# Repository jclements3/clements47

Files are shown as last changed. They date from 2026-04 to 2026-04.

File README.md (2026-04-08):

# Clements47 Harp

A parametric Erard concert harp modeled in FreeCAD 1.1, with a soundbox defined by limacon cross-sections.

## Soundbox Surface Generation

The soundbox is defined by two planar curves and a family of limacon cross-sections swept between them.

### 1. Soundboard Curve (Limacon Origins)

A clamped cubic spline through 11 nodes with vertical takeoff (dx/dt = 0) at both endpoints.

**Nodes (base to neck):**

| # | Point | Description |
|---|---|---|
| 1 | (7.0, -65.6486) | Base — 3" left, 6" below C1 grommet |
| 2 | bass extension | 2" beyond string 1 along tangent |
| 3 | (10.0, -59.6486) | Grommet — string 1 (C1) |
| 4 | (14.943, -51.8946) | Grommet — string 8 |
| 5 | (20.512, -36.3672) | Grommet — string 16 |
| 6 | (25.476, -19.0939) | Grommet — string 24 |
| 7 | (30.076, -10.2416) | Grommet — string 32 |
| 8 | (34.313, -5.2852) | Grommet — string 40 |
| 9 | (37.986, -2.3942) | Grommet — string 47 (G7) |
| 10 | treble extension | 2" beyond string 47 along tangent |
| 11 | (40.3802, 0.0) | Neck — G7 string length right of G7 pin |

**Extension points** are computed from the tangent direction between the first/last two grommet nodes, extended 2" outward.

**Boundary conditions:** `bc_type=((1, 0.0), (1, 0.0))` for x(t), `bc_type=((1, v), (1, v))` for y(t), where v is the average parametric speed. This forces the curve to depart vertically at both the base and neck, ensuring the limacon cross-sections there lie flat (horizontal).

### 2. Cusp Curve (Limacon Cusps)

A clamped cubic spline through 9 nodes, also with vertical takeoff at both endpoints.

The 9 nodes are sampled from 51 cusp points. To compute each cusp point:

1. Evaluate the soundboard curve at the corresponding parameter value
2. Compute the unit tangent **(tx, ty)** and right-hand normal **(ty, -tx)**
3. Interpolate the limacon diameter linearly:
   - **18"** at the base (x = 7.0)
   - **4"** at the neck (x = 40.3802)
4. Compute **b = diameter / 6** (the polar axis length, since a = 2b)
5. Offset: **cusp = origin + b * right_normal**

The 9 nodes are taken at indices [0, 6, 12, 19, 25, 31, 37, 44, 50] of the 51 cusp points.

### 3. Limacon Cross-Sections

Each cross-section is a limacon of Pascal: **r(theta) = a + b * cos(theta)**

Given a pair of corresponding points (origin on soundboard curve, cusp on cusp curve):

- **b** = distance(origin, cusp) = polar axis length
- **a** = 2b (the a = 2b constraint ensures a smooth D-shape with no inner loop)
- **Polar axis direction** = unit vector from origin toward cusp
- **Limacon plane** is perpendicular to the soundboard tangent at that point

Orientation:
- **theta = 0**: points opposite the cusp (toward the strings / bulge side), r = a + b = 3b
- **theta = pi**: points toward the cusp, r = a - b = b

The 3D transformation for each point on the limacon:

```
u = r(theta) * cos(theta)    # component along polar axis (in XY plane)
v = r(theta) * sin(theta)    # component along Z axis

x = origin_x + u * (-polar_dir_x)
y = origin_y + u * (-polar_dir_y)
z = v
```

Where `polar_dir` is the unit vector from origin to cusp (so `-polar_dir` points toward the bulge at theta = 0).

### 4. Limacon Dimensions

| Property | Formula | Base (18" dia) | Neck (4" dia) |
|---|---|---|---|
| Diameter (max width) | 2(a + b) = 6b | 14" | 4" |
| Depth (along polar axis) | 4b | 9.3" | 2.67" |
| Bulge radius (theta=0) | a + b = 3b | 7" | 2" |
| Cusp distance (theta=pi) | a - b = b | 2.33" | 0.667" |
| Perpendicular width | 2a = 4b | 9.3" | 2.67" |
| Aspect ratio (width:depth) | 6b : 4b | 3:2 | 3:2 |

### 5. Acoustic Analysis

#### Volume and Helmholtz Resonance

| Property | Clements47 | Lyon & Healy 23 | Salvi Aurora |
|---|---|---|---|
| Soundbox volume | **43 L** | ~35-40 L | ~35-40 L |
| Helmholtz frequency | **85 Hz (E2)** | ~90-110 Hz | ~90-110 Hz |
| Base width | 14" | ~14-16" | ~14-16" |
| Total tension | 1,466 lbs | ~1,800 lbs | ~1,700 lbs |
| Cross-section | Limaçon (D-shape) | Round/Oval | Round/Oval |
| String material | Nylon/Wire | Gut/Wire | Gut/Wire |

#### Volume Distribution

| Region | Volume | Share |
|---|---|---|
| Base (0-15") | 1,628 in³ | 40% |
| Bass (15-30") | 1,127 in³ | 28% |
| Mid (30-50") | 882 in³ | 22% |
| Treble (50-65") | 315 in³ | 8% |
| Neck (65-75") | 97 in³ | 2% |

#### Soundboard Loading

- String angle from soundboard: 34°
- Vertical load: 820 lbs (56% of tension)
- Horizontal compression: 1,215 lbs (83% of tension)

#### Tonal Character

- **Warmer and rounder** than modern gut-strung concert harps
- **Enhanced bass** due to ~43L volume (1.2x modern harps)
- **Lower Helmholtz resonance** (~85 Hz vs 90-110 Hz) supports lower strings
- **D-shape projects directionally** — cusp acts as reflector toward player
- **Lighter tension** (1,466 lbs) allows thinner, more responsive soundboard
- Nylon strings: even decay across registers, less sustain than gut

#### Design Recommendations

- **Soundholes**: 2 holes (~3" dia) in the cusp (back), near strings 30-35
- **Soundboard**: Spruce, ~3mm (thinner than modern 4-5mm due to lower tension)
- **Bracing**: Minimal — limaçon cusp line provides natural stiffness
- **Back/ribs**: Maple, steam-bent or laminated to limaçon profile
- **Optional soundpost**: Bass end, connecting soundboard to cusp (violin-like coupling)

### 6. Lofting

50 limacon cross-sections are sampled evenly along the soundboard curve parameter and lofted into a solid using FreeCAD's `Part::Loft` with `Solid = True, Ruled = False`.

## Files

| File | Description |
|---|---|
| `erard_harp.FCMacro` | Stringband sketch (47 strings, keys, soundboard B-spline) |
| `erard_soundbox.FCMacro` | Soundbox generation (limacon cross-sections, loft) |
| `erard_harp.FCStd` | FreeCAD project with stringband sketch |
| `Clements47.FCStd` | FreeCAD project with soundbox |
| `erard%20original%20stringband%20tutorial.dxf` | Source string positions (harpcanada.com) |
| `soundboard_curve.svg` | 2D visualization of soundboard + cusp curves |

## Parameters

| Parameter | Value |
|---|---|
| Strings | 47 (C1 to G7) |
| String lengths | 59.65" (C1) to 2.39" (G7) |
| Base diameter | 14" |
| Neck diameter | 4" |
| Limacon ratio | a = 2b |
| Diameter taper | Linear |
| Extension length | 2" at each end |
| Base point offset | (-3, -6) from C1 grommet |
| Neck point offset | (+2.3942, 0) from G7 pin |
| Soundboard nodes | 11 (clamped cubic spline) |
| Cusp nodes | 9 (clamped cubic spline) |
| Cross-sections | 50 |
| Takeoff angles | 90" (vertical) at base and neck |

## Stringband Data

Source: [harpcanada.com/harpmaking/erard.htm](https://harpcanada.com/harpmaking/erard.htm)

### Note Map (47 strings, highest to lowest)

| Str# | Note | Octave | Material | Color | Spacing Group |
|---|---|---|---|---|---|
| 1 | G | 0 | Nylon | white | 0.706" |
| 2 | F | 0 | Nylon | blue | 0.706" |
| 3 | E | 1st | Nylon | white | 0.706" |
| 4 | D | 1st | Nylon | white | 0.706" |
| 5 | C | 1st | Nylon | **red** | 0.706" |
| 6 | B | 1st | Nylon | white | 0.706" |
| 7 | A | 1st | Nylon | white | 0.706" |
| 8 | G | 1st | Nylon | white | 0.706" |
| 9 | F | 1st | Nylon | blue | 0.706" |
| 10 | E | 2nd | Nylon | white | 0.706" |
| 11 | D | 2nd | Nylon | white | 0.706" |
| 12 | C | 2nd | Nylon | **red** | 0.686" |
| 13 | B | 2nd | Nylon | white | 0.686" |
| 14 | A | 2nd | Nylon | white | 0.686" |
| 15 | G | 2nd | Nylon | white | 0.686" |
| 16 | F | 2nd | Nylon | blue | 0.646" |
| 17 | E | 3rd | Nylon | white | 0.646" |
| 18 | D | 3rd | Nylon | white | 0.646" |
| 19 | C | 3rd | Nylon | **red** | 0.606" |
| 20 | B | 3rd | Nylon | white | 0.606" |
| 21 | A | 3rd | Nylon | white | 0.606" |
| 22 | G | 3rd | Nylon | white | 0.606" |
| 23 | F | 3rd | Nylon | blue | 0.606" |
| 24 | E | 4th | Nylon | white | 0.565" |
| 25 | D | 4th | Nylon | white | 0.565" |
| 26 | C | 4th | Nylon | **red** | 0.565" |
| 27 | B | 4th | Nylon | white | 0.565" |
| 28 | A | 4th | Nylon+wrap | white | 0.565" |
| 29 | G | 4th | Nylon+wrap | white | 0.565" |
| 30 | F | 4th | Nylon+wrap | blue | 0.565" |
| 31 | E | 5th | Nylon+wrap | white | 0.565" |
| 32 | D | 5th | Nylon+wrap | white | 0.565" |
| 33 | C | 5th | Nylon+wrap | **red** | 0.565" |
| 34 | B | 5th | Nylon+wrap | white | 0.525" |
| 35 | A | 5th | Nylon+wrap | white | 0.525" |
| 36 | G | 5th | Nylon+wrap | white | 0.525" |
| 37 | F | 5th | Nylon+wrap | blue | 0.525" |
| 38 | E | 6th | Nylon+wrap | white | 0.525" |
| 39 | D | 6th | Steel/Bronze | white | 0.525" |
| 40 | C | 6th | Steel/Bronze | **red** | 0.525" |
| 41 | B | 6th | Steel/Bronze | white | 0.525" |
| 42 | A | 6th | Steel/Bronze | white | 0.525" |
| 43 | G | 6th | Steel/Bronze | white | 0.525" |
| 44 | F | 6th | Steel/Bronze | blue | 0.525" |
| 45 | E | 7th | Steel/Bronze | white | 0.525" |
| 46 | D | 7th | Steel/Bronze | white | 0.525" |
| 47 | C | 7th | Steel/Bronze | **red** | — |

### String Materials (Erard Specification)

| Register | Strings | Construction | Core Dia | Outer Dia | Tension Range |
|---|---|---|---|---|---|
| Treble | 1-7 | Plain nylon | 0.025" | 0.025" | 11-15 lbs |
| Upper-mid | 8-14 | Plain nylon | 0.028-0.032" | 0.028-0.032" | 16-21 lbs |
| Mid | 15-27 | Plain nylon | 0.036-0.050" | 0.036-0.050" | 20-29 lbs |
| Lower-mid | 28-38 | Nylon core + nylon wrap | 0.045-0.060" | 0.061-0.104" | 33-49 lbs |
| Bass | 39-47 | Steel core + bronze wrap | 0.020-0.026" | 0.046-0.091" | 49-53 lbs |

Material transitions: string 28 (plain nylon → wound nylon), string 39 (nylon → steel/bronze).

### String Tension (Erard)

| Property | Value |
|---|---|
| Total soundboard load | 1,466 lbs (665 kg) |
| Per-string range | 11-53 lbs |
| Mean per-string | 31.2 lbs |
| Max tension jump | 6.5 lbs (strings 27→28) |

### Color Coding

- **Red**: C strings (strings 5, 12, 19, 26, 33, 40, 47)
- **Blue/Black**: F strings (strings 2, 9, 16, 23, 30, 37, 44)
- **White**: All other notes

### Material Properties

| Material | Density (kg/m³) | Tensile Strength (psi) |
|---|---|---|
| Nylon (Tynex) | 1,067 | 44,600 |
| Steel music wire | 7,830 | 325,000 |
| Bronze (phosphor) | 8,850 | 140,000 |

### US String Sources

| Strings | Source | Product | Est. Cost |
|---|---|---|---|
| 1-27 (plain nylon) | [Dusty Strings](https://manufacturing.dustystrings.com/harps/strings) (Seattle) | Monofilament by diameter, .025"-.050" | ~$95 |
| 28-38 (nylon wound) | [Musicmakers/HarpKit](https://www.harpkit.com/harp-strings) (Stillwater MN) | "NN" type — nylon core + nylon wrap | ~$185-350 |
| 39-47 (steel/bronze) | [Musicmakers/HarpKit](https://www.harpkit.com/harp-strings) | "SFB" type — steel core + bronze wrap | Contact |
| 39-47 (alternative) | [Vanderbilt Music](https://vanderbiltmusic.com/harp-strings/vanderbilt-bass-wires/) | Tarnish-resistant wires, $17.25/ea | ~$155 |
| Historical option | [Aquila Corde](https://aquilacorde.com/en/early-music-strings/synthetic/empire-period-harp-bass-wound-strings-as-type/) (Italy) | Silk/Nylgut core, silvered copper | ~$28-32/ea |

Estimated full set: **$435-600**

### References

- [HarpCanada - Erard Stringband](https://harpcanada.com/harpmaking/erard.htm) — original Erard string specifications
- [HarpCanada - StringBand Manager](https://www.harpcanada.com/stringband.htm)
- [Harp Connection - 47 String Chart](https://www.harpconnection.com/PDF%20String%20Charts/String%20Chart%20Pedal%2047.pdf)
- [Sligo Harps - String Theory](http://www.sligoharps.com/string.html)
- [Metropolitan Museum - Erard String Gauge 1829](https://www.metmuseum.org/art/collection/search/504046)

## Running

Requires FreeCAD 1.1 with Python 3.11 and scipy:

```bash
# Using extracted AppImage
export LD_LIBRARY_PATH=./squashfs-root/usr/lib:$LD_LIBRARY_PATH
./squashfs-root/usr/bin/freecadcmd -c "exec(open('erard_soundbox.FCMacro').read())"
```

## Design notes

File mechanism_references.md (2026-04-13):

# Mechanism Reference Notes — Compiled 2026-04-12

Synthesized from Erard book, Buckwell patent, Salvi manual, Camac manual,
and web sources. For designing bell cranks, linkage rods, and pedal action
in Clements47.FCStd.

## Reference PDFs in this repo

- `erard_grecian_harp.pdf` — Poulopoulos 2023 (319pp, CC-BY-NC-ND 4.0).
  Full history of Erard Grecian harp mechanism. Key pages:
  - p.28 Figure 4: 1810 patent drawings for double-action fourchettes
  - p.39 Figure 7: brass plate mechanism photo (Erard No.2631)
  - pp.31-32: dead centre toggle linkage description
  - pp.22-25: Empire model fourchettes, brass plate mounting
  - p.42: Grecian harp dimensions (1700x360x830mm, 43 strings, ~20kg)
- `salvi_technical_manual.pdf` — Salvi official tech manual (24pp).
  Key pages:
  - pp.8-9: structure diagram + mechanism diagram (action plates, discs)
  - pp.12-14: "How a Harp Works" — complete mechanical chain diagram
  - p.14: disc engagement illustration (flat/natural/sharp positions)
- `camac_technical_manual.pdf` — Camac owner's manual (38pp).
  Key pages:
  - p.4: nomenclature with photo labels (A=pin, B=nut, C=natural disc, D=sharp disc)
  - pp.13-15: dead point adjustment, cable length, rod-tuner procedure
  - pp.17-20: disc regulation, friction cone attachment, set screw details
  - p.19: sharp discs have LEFT-HAND threads (critical!)

## Complete Mechanical Chain (modern Salvi/Camac)

```
PEDAL (3 grooves in base: flat / natural / sharp)
  |-- pedal spring (returns pedal upward)
  |-- felt cushion (dampens impact at each groove)
  v
PEDAL ROD COUPLING (screw at base, 2.5mm Allen adjustable)
  v
PEDAL ROD (steel, slides vertically inside column)
  v
ACTION COUPLING (at top of column, 5mm Allen bolt)
  v
MAIN ACTION GROUP (inside neck, distributes to 7 note lines)
  |-- 7 upper lines (natural, "becarre")
  |-- 7 lower lines (sharp, "diese")
  v
LEVERS (slide between two brass action plates)
  |-- connection levers: high-strength steel
  |-- sliding parts: copper-zinc alloy
  v
DISC SPINDLES (rotate in action plate bearings)
  |-- conical end extends through front plate
  |-- friction cone locks disc to spindle
  |-- set screw secures (CW for natural, CCW/LH for sharp!)
  v
DISCS (brass, with 2 prongs each)
  |-- natural disc: upper row
  |-- sharp disc: lower row
  |-- prongs grip string when rotated to 12:30 position
```

## Key Engineering Principles

### Dead Point / Dead Centre (Camac pp.13-14, Erard pp.31-32)

The "dead point" is the precise moment where:
- Natural discs STOP turning and reach maximum grip on strings
- Sharp discs BEGIN turning

This must coincide EXACTLY with the natural pedal position in the base.
If the cable stretches, the dead point drifts (called "overmotion"):
- Natural discs don't fully engage at natural position
- Result: bad intonation + buzzing

**For Clements47 toggle linkage**: The dead point is inherent in the
over-center geometry. The compound bell crank arm angle (~90 deg)
creates a natural dead center when one chain reaches full extension
and the other chain's linkage passes through its straight-line position.

### Disc Rotation Angles (USC/illumin article)

- Flat -> Natural: upper disc rotates ~45 deg CW to engage
- Flat -> Natural: lower disc rotates ~45 deg but does NOT touch string
- Natural -> Sharp: lower disc rotates additional ~35 deg to engage
- Total lower disc travel: ~80 deg (45 + 35)

### Disc Attachment — Friction Cone (Camac p.17)

- Spindle has conical taper extending through front action plate
- Cone inserts into disc bore
- Tightening screw wedges disc onto cone
- Friction alone holds disc — removing screw won't free it
- To free: lever screwdriver between prongs, pop cone loose
- Natural discs: right-hand threads (normal)
- Sharp discs: LEFT-HAND threads (reversed!)

### Disc Sizes — Four Families (Camac pp.18-20)

1. Natural notes E43 to E8 (large discs, 2 prongs)
2. Sharp notes E43 to E8 (large discs, 2 prongs, LH threads)
3. Natural notes F7 to F0 (small discs, 1 prong only — space constraint)
4. Sharp notes F7 to F0 (small discs, 1 prong, LH threads)

### Regulation Tools (Camac p.7)

- 4mm slot screwdriver: large discs
- 2.5mm slot screwdriver: medium discs
- 2.0mm slot screwdriver: small discs
- 2.5mm Allen key: cable length adjustment + large string nuts
- 2.0mm Allen key: small string nuts
- 5.0mm Allen key: column top attachment screws

## Buckwell Patent US1332885A (1920) — Component Architecture

Buckwell's patent for a hand-operated harp action provides the clearest
"exploded view" of the rocker-crank-shaft-disc chain:

| Ref | Part | Function |
|-----|---|---|
| 5 | Combs | Brass mounting plates (= front/back action plates) |
| 7 | Perforated plate | Top plate where rockers sit |
| 8 | Rocker | Input lever (= bell crank at input) |
| 9 | Upright stem | Rocker handle |
| 10 | Lateral base | Rocker pivot platform |
| 11 | Central pivot | Rocker pivot point |
| 12 | Link | Linkage rod (connects rocker to crank) |
| 14 | Crank | Drive crank fixed to shaft |
| 16 | Coil spring | Return spring on link |
| 17 | Shaft | Disc axle (journaled in combs) |
| 18 | Screw cup | Axle bearing mount |
| 20 | Disk | Tuning disc |
| 21 | Fingers | Prongs / pins on disc |
| 22 | Vertical crank | Compound bell crank for multi-octave |
| 23,24 | Links | Chain linkage rods (different cross-sections: tension vs compression) |

**Key detail**: Links 23 and 24 have DIFFERENT cross-sections because
"one acts in tension and the other in compression."

## Erard Grecian Harp Dimensions (Poulopoulos p.42)

- Height: 1,700 mm
- Soundboard width: 360 mm
- Depth (capital to shoulder): 830 mm
- Strings: 43 (gut treble, silk/brass bass)
- Weight: ~20 kg
- Mechanism: enclosed between 2 brass plates on neck
- Pedals: 7 single-arm with springs, zigzag notches
- Total string tension: ~1,200 kg (Salvi concert grand)

## Erard Historical Mechanism Details (Poulopoulos pp.22-32)

### Fourchettes (Discs)
- First patented 1794 (single action)
- Double-action patent 1810 (No. 3332)
- Enclosed between two brass plates screwed to neck
- Back covered by removable wooden panel
- Adjustable brass nuts with horizontal screws for intonation
- On Grecian: nuts face toward SHOULDER (reversed from Empire)
- First 12 bass strings: no adjustable nuts
- Last treble string: no fourchette AND no adjustable nut

### Mechanism Simplicity (1823 review, p.32)
"Five pieces only are employed: the flat plate or disk, and prongs,
are two, and the motion distributed form one axis only."

Per string, only 5 parts: disc body + 2 prongs + axle + set screw

### Construction Materials (Salvi manual p.6)
- Connection levers: high-strength steel
- Sliding parts: copper-zinc alloy (wear resistance)
- Action plates: special brass
- Neck: high-strength beech + maple plywood
- Column: solid Canadian maple
- Soundboard: Fiemme Valley red spruce

## Mapping to Clements47 Design

### What EXISTS in the model (448 objects via add_mechanism.py):
- 47 strings (Str_C1 through Str_G7)
- 47 axles (Axle_C1 through Axle_G7), 44mm, 4-8mm dia
- 94 discs (NatDisc_*, ShpDisc_*), 4.27-25mm radius
- 188 prongs (NatPrU/D_*, ShpPrU/D_*), M3, 12.7mm ext
- 1 neck (720x200x250mm hollow box)

### What NEEDS to be added:
1. Bell cranks — compound (natural + sharp arms at ~90 deg)
2. Linkage rods — connect bell cranks along each note's chain
3. Front/back action plates — brass, hold spindle bearings
4. Pedal rods — steel, inside column
5. Column — structural tube
6. Pedal assembly — 7 pedals with springs and zigzag notches
7. Disc rotation stops — limit to ~45 deg
8. Return springs — at each link/rocker

### Design Sequence for Next Session:
1. Define bell crank geometry (arm lengths, pivot locations, angles)
2. Calculate linkage rod lengths from string spacing data
3. Add bell cranks to add_mechanism.py
4. Add linkage rods to add_mechanism.py
5. Add action plates (front/back brass plates)
6. Add pedal rods and column
7. Animate the 3-position cycle for verification

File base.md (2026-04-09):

# Harp Base - Bottom View

This diagram shows the harp pedal mechanism as viewed from **below the harp, looking up from the floor**.

## Pedal Positions and String Pitch

Each pedal has three positions controlled by notches in the pedal slot:

| Position | Pedal State | String Pitch | Disc Rotation | Vertical Rod |
|---|---|---|---|---|
| **Up** | Flat (â™­) | Lowest | 0Â° (disengaged) | Lowest position |
| **Middle** | Natural (â™®) | Middle | 45Â° (first prong engages) | Middle position |
| **Down** | Sharp (â™¯) | Highest | 90Â° (second prong engages) | Highest position |

## Lever Mechanics

The pedal mechanism uses **bell cranks** to convert horizontal pedal motion into vertical rod motion inside the pillar.

### Motion Transfer

```
PEDAL (horizontal)     BELL CRANK (pivot)     VERTICAL ROD (in pillar)
      â†â†’          â†’      â†º              â†’           â†‘â†“
   Push/Pull           Rotate                  Rise/Fall
```

### Mechanical Advantage

| Parameter | Value |
|---|---|
| Pedal travel per notch | ~30mm |
| Vertical rod displacement | ~12mm |
| **Lever ratio** | **2.5:1** |
| Bell crank input arm | 25mm |
| Bell crank output arm | 10mm |

The 2.5:1 ratio means:
- Pressing the pedal **30mm** produces **12mm** of vertical rod travel
- This 12mm is sufficient to rotate the semitone discs through their engagement positions

## What Happens When You Press a Pedal

### Flat â†’ Natural (pedal moves from UP to MIDDLE)

1. Player presses pedal down by ~30mm into middle notch
2. Horizontal pedal rod **pulls inward** toward pillar
3. Bell crank **rotates** around its pivot point
4. Output arm pushes vertical rod **up** by ~12mm
5. Action rod rises through pillar and neck
6. First disc (natural disc) rotates from 0Â° to 45Â°
7. Prong engages string, **shortening vibrating length**
8. String pitch **rises one semitone** (e.g., Câ™­ â†’ Câ™®)

### Natural â†’ Sharp (pedal moves from MIDDLE to DOWN)

1. Player presses pedal down another ~30mm into bottom notch
2. Horizontal rod pulls inward another ~30mm
3. Bell crank rotates further
4. Vertical rod rises another ~12mm (total ~24mm from flat)
5. Second disc (sharp disc) rotates from 45Â° to 90Â°
6. Second prong engages string, **shortening it further**
7. String pitch **rises another semitone** (e.g., Câ™® â†’ Câ™¯)

### Return Springs

Each bell crank has a **torsion spring** that:
- Biases the mechanism toward the "up" (flat) position
- Provides tactile resistance so the player can feel notch positions
- Returns the pedal if released (though pedals lock in notches)

## Diagram Elements

- **Red lines**: Pedal rods from pedal to bell crank input arm
- **Blue arc**: Bell crank pivot points (where cranks mount to pillar base)
- **Blue lines**: Bell crank input arms (toward pedals)
- **Orange lines**: Bell crank output arms (toward pillar center)
- **Orange circle**: Vertical rod entry points into pillar
- **Red polyline**: Base frame structural outline

### Pedal Arrangement

- **Left foot** (3 pedals): D, C, B
- **Right foot** (4 pedals): E, F, G, A

Note: There is a gap between B and E to accommodate the player's feet.

## Coordinate System

- Units: 1/100 mm (so 10000 = 100mm = 10cm)
- ViewBox: 215.9mm x 279.4mm (letter size)
- Origin (0,0): Top-left corner
- Pillar center: approximately (9300, 2100)

## Diagram

```svg
<?xml version="1.0" encoding="UTF-8"?>
<svg xmlns="http://www.w3.org/2000/svg" viewBox="0 0 21590 27940" width="215.9mm" height="279.4mm">
  <!--
    Harp Base - Bottom View (looking up from floor)
    Units: 1/100 mm

    Lever system: Bell cranks at pivot arc convert horizontal pedal
    motion to vertical rod motion in pillar.

    Lever ratio 2.5:1: 30mm pedal travel â†’ 12mm rod displacement
  -->

  <!-- Pillar center reference -->
  <circle cx="9300" cy="2100" r="100" fill="#888" opacity="0.5"/>

  <!-- Bell crank pivot arc (R=1600, where cranks mount) -->
  <path d="M 7700,2100 A 1600 1600 0 0 1 10900,2100"
        stroke="#0066cc" stroke-width="60" fill="none"/>

  <!-- 7 pedal rods (pedal position to bell crank input arm end) -->
  <!-- D: angle -56Â° from pillar -->
  <line x1="2100" y1="5600" x2="7980" y2="2990" stroke="red" stroke-width="51"/>
  <!-- C: angle -42Â° -->
  <line x1="3700" y1="7300" x2="8230" y2="3170" stroke="red" stroke-width="51"/>
  <!-- B: angle -28Â° -->
  <line x1="5750" y1="8600" x2="8550" y2="3310" stroke="red" stroke-width="51"/>
  <!-- E: angle +14Â° -->
  <line x1="8050" y1="9050" x2="9690" y2="3340" stroke="red" stroke-width="51"/>
  <!-- F: angle +30Â° -->
  <line x1="13100" y1="8500" x2="10100" y2="3240" stroke="red" stroke-width="51"/>
  <!-- G: angle +46Â° -->
  <line x1="15100" y1="6950" x2="10450" y2="3050" stroke="red" stroke-width="51"/>
  <!-- A: angle +60Â° -->
  <line x1="16700" y1="5300" x2="10690" y2="2760" stroke="red" stroke-width="51"/>

  <!-- Bell crank pivot points (on the arc) -->
  <circle cx="7980" cy="2590" r="80" fill="#0066cc"/>  <!-- D -->
  <circle cx="8230" cy="2770" r="80" fill="#0066cc"/>  <!-- C -->
  <circle cx="8550" cy="2910" r="80" fill="#0066cc"/>  <!-- B -->
  <circle cx="9690" cy="2940" r="80" fill="#0066cc"/>  <!-- E -->
  <circle cx="10100" cy="2840" r="80" fill="#0066cc"/> <!-- F -->
  <circle cx="10450" cy="2650" r="80" fill="#0066cc"/> <!-- G -->
  <circle cx="10690" cy="2360" r="80" fill="#0066cc"/> <!-- A -->

  <!-- Bell crank input arms (from pivot toward pedal, length=2500) -->
  <line x1="7980" y1="2590" x2="7980" y2="2990" stroke="#0066cc" stroke-width="80"/>
  <line x1="8230" y1="2770" x2="8230" y2="3170" stroke="#0066cc" stroke-width="80"/>
  <line x1="8550" y1="2910" x2="8550" y2="3310" stroke="#0066cc" stroke-width="80"/>
  <line x1="9690" y1="2940" x2="9690" y2="3340" stroke="#0066cc" stroke-width="80"/>
  <line x1="10100" y1="2840" x2="10100" y2="3240" stroke="#0066cc" stroke-width="80"/>
  <line x1="10450" y1="2650" x2="10450" y2="3050" stroke="#0066cc" stroke-width="80"/>
  <line x1="10690" y1="2360" x2="10690" y2="2760" stroke="#0066cc" stroke-width="80"/>

  <!-- Bell crank output arms (from pivot toward pillar center, length=1000) -->
  <line x1="7980" y1="2590" x2="8550" y2="2340" stroke="#cc6600" stroke-width="80"/>
  <line x1="8230" y1="2770" x2="8720" y2="2480" stroke="#cc6600" stroke-width="80"/>
  <line x1="8550" y1="2910" x2="8940" y2="2580" stroke="#cc6600" stroke-width="80"/>
  <line x1="9690" y1="2940" x2="9510" y2="2490" stroke="#cc6600" stroke-width="80"/>
  <line x1="10100" y1="2840" x2="9780" y2="2430" stroke="#cc6600" stroke-width="80"/>
  <line x1="10450" y1="2650" x2="10020" y2="2320" stroke="#cc6600" stroke-width="80"/>
  <line x1="10690" y1="2360" x2="10180" y2="2150" stroke="#cc6600" stroke-width="80"/>

  <!-- Vertical rod entry points (inner circle, where rods go up pillar) -->
  <circle cx="9300" cy="2100" r="600" stroke="#cc6600" stroke-width="40" fill="none"/>

  <!-- Base frame outline -->
  <polyline points="4600,3400 5400,5800 6700,6900 8300,7650 10300,7650 12100,6900 13400,5550 14100,3400 13900,3250 10900,1350 7600,1400 4600,3400"
            stroke="red" stroke-width="51" fill="none"/>

  <!-- Labels -->
  <text x="1800" y="5400" font-size="400" fill="#666">D</text>
  <text x="3400" y="7100" font-size="400" fill="#666">C</text>
  <text x="5450" y="8400" font-size="400" fill="#666">B</text>
  <text x="8100" y="9400" font-size="400" fill="#666">E</text>
  <text x="13300" y="8700" font-size="400" fill="#666">F</text>
  <text x="15300" y="7150" font-size="400" fill="#666">G</text>
  <text x="16900" y="5500" font-size="400" fill="#666">A</text>
</svg>
```

## Physics Summary

### Force Chain

```
Player's foot
    â†“
Pedal (lever arm ~150mm from pivot)
    â†“
Horizontal pedal rod (push/pull)
    â†“
Bell crank input arm (25mm)
    â†“ (pivot rotation)
Bell crank output arm (10mm)
    â†“
Vertical action rod (rises in pillar)
    â†“
Disc axle (rotates disc)
    â†“
Prong engages string (shortens vibrating length)
    â†“
Pitch increases by one semitone
```

### Energy Consideration

- Player exerts ~20-50N on pedal
- Pedal mechanical advantage: ~3:1 (foot lever)
- Bell crank ratio: 2.5:1
- Combined ratio: ~7.5:1
- Force at disc: ~150-375N (sufficient to deflect string ~1.5mm)

### Vibrating Length Change

For a semitone (ratio 2^(1/12) â‰ˆ 1.0595):
- Original length L produces frequency f
- Shortened length L/1.0595 produces frequency f Ã— 1.0595
- For a 1000mm string: ~56mm shorter per semitone
- Disc prong deflection provides this shortening

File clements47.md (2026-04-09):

# CLEMENTS47 Harp Design Document

## Toggle Linkage Over-Center Mechanism

-----

## Executive Summary

The CLEMENTS47 is a revolutionary 47-string pedal harp featuring a **toggle linkage mechanism** with dual natural and sharp chains. This over-center mechanism enables sequential disc engagement through clever geometry rather than complex detents, creating a reliable and elegant sharping system.

**Key Innovation:** Locomotive-style coupling links between natural and sharp chains create toggle positions that allow the natural chain to move first (pedal position 0→1), hold position while the sharp chain moves (1→2), creating three distinct pitch positions without requiring detents at each disc.

-----

## I. Fundamental Design Principles

### 1.1 String Architecture

- **47 strings** spanning C1 (32.7 Hz) to G7 (3136 Hz)
- **Straight-line arrangement** along X-axis (crown to shoulder)
- **Vertical orientation** in playing position (parallel to Z-axis)
- **Physics-optimized tensioning** ranging from 48.8N (G7) to 236.7N (A1)
- **Three pitches per string:** Flat, Natural, Sharp

### 1.2 Coordinate System

```
X-axis: Crown (bass, 0mm) → Shoulder (treble, 721mm)
Y-axis: Harpist (-Y) ← Soundboard (0) → Audience (+Y)  
Z-axis: Floor (0mm) → Vertical up (+Z)
```

### 1.3 Material Philosophy

- **316 Stainless Steel:** Disc axles, prongs, hardware
- **Carbon fiber composite:** Neck structure, soundboard
- **Aluminum 6061-T6:** Bell cranks, linkage components
- **Bronze-wrapped nylon:** Bass strings
- **Nylon monofilament:** Treble strings

-----

## II. The Toggle Linkage Mechanism

### 2.1 Mechanism Type

**Over-Center Toggle Linkage** (Four-Bar Linkage with Sequential Actuation)

This mechanism uses compound bell cranks with arms arranged approximately 90° apart, creating toggle positions that enable sequential motion without requiring detents at each disc location.

### 2.2 The Three Pedal Positions

**Position 0 (Flat):**

- Natural discs: 9:15 position (disengaged)
- Sharp discs: 9:15 position (disengaged)
- Both chains at rest
- Prongs clear string on both sides

**Position 1 (Natural):**

- Natural discs: 12:30 position (engaged ~45° rotation)
- Sharp discs: 9:15 position (still disengaged)
- Natural chain has moved, sharp chain remains at rest
- Natural disc prongs engage string from above/below at angle
- Toggle geometry holds natural chain in place

**Position 2 (Sharp):**

- Natural discs: 12:30 position (held by geometry)
- Sharp discs: 12:30 position (engaged ~45° rotation)
- Sharp chain has now moved
- Both sets of prongs at 12:30 position
- Sharp disc prongs engage string, natural prongs still present but sharp dominates

### 2.3 Sequential Motion Principle

The genius of the toggle linkage is that **disc rotation is limited to approximately 45°** (not a full 90° or continuous rotation). The discs **rock back and forth** rather than spin continuously.

**Transition 0→1:**

1. Pedal input begins to move
1. Compound bell crank geometry causes natural chain to rotate
1. Natural discs rock from 9:15 → 12:30 (~45° clockwise)
1. Sharp chain remains stationary (near its geometric dead center)
1. Natural discs engage string

**Transition 1→2:**

1. Pedal continues to move
1. Natural chain reaches toggle point (geometric lock)
1. Compound bell crank now drives sharp chain
1. Sharp discs rock from 9:15 → 12:30 (~45° clockwise)
1. Natural discs held at 12:30 by toggle geometry
1. Sharp discs engage string

**Transition 2→1 (Return):**

1. Pedal reverses direction
1. Sharp chain rotates back 9:15
1. Natural chain remains at 12:30 (held by toggle)
1. Sharp discs disengage

**Transition 1→0 (Full Return):**

1. Pedal returns to rest
1. Natural chain rotates back to 9:15
1. Both chains at rest position

-----

## III. Mechanical Components

### 3.1 Dual Chain System

Each of the 7 notes (C, D, E, F, G, A, B) has **two parallel chains:**

**Natural Chain:**

- Master bell crank at crown/input
- Linkage rod
- Bell crank for string 1 (natural disc)
- Linkage rod
- Bell crank for string 2 (natural disc)
- Linkage rod
- … continues through all strings of that note
- Final bell crank at shoulder

**Sharp Chain:**

- Bell crank for string 1 (sharp disc)
- Linkage rod
- Bell crank for string 2 (sharp disc)
- Linkage rod
- … continues through all strings of that note

### 3.2 Compound Bell Cranks (Coupling Linkages)

At each string position, a **compound bell crank** connects the natural and sharp chains. This is the key component that creates the toggle action.

**Design:**

- Two arms arranged approximately 90° apart
- One arm connects to natural chain
- Other arm connects to sharp chain
- Pivot bearing at center
- **Locomotive-style coupling** between chains

**Function:**

- As natural arm sweeps through large arc, sharp arm barely moves (near dead center)
- At toggle point, geometry reverses
- As sharp arm sweeps through large arc, natural arm barely moves (near its dead center)

### 3.3 Bell Crank Specifications

**Material:** Aluminum 6061-T6 or steel plate
**Thickness:** 5-10mm
**Pivot bearing:** Needle bearing or bronze bushing, 6-10mm diameter
**Connection method:** Pinned connections with clevis pins (3-4mm diameter)
**Arm lengths:** Vary by string position (shorter arms for treble strings)

### 3.4 Linkage Rods

**Material:** 316 Stainless Steel or aluminum
**Diameter:** 3-6mm depending on load
**Length:** Varies by string spacing (13.3mm to 17.9mm between strings)
**End connections:** Rod end bearings (heim joints) or clevis pins
**Thread:** M6×1.0 LH/RH for length adjustment where needed

-----

## IV. Disc and Axle System

### 4.1 Disc Axle Configuration

**Total disc axles:** 47 (one per string)
**Axle orientation:** Parallel to Y-axis (horizontal, perpendicular to strings)
**Axle material:** 316 Stainless Steel
**Axle diameters:** 4mm, 5mm, 6mm, or 8mm depending on torque requirements

**Alternating sides:**

- Odd string numbers (1, 3, 5…47): Left side, extends toward harpist (-Y), offset -15mm
- Even string numbers (2, 4, 6…46): Right side, extends toward audience (+Y), offset +15mm
- **Purpose:** Prevent bearing interference at tight string spacing

### 4.2 Disc Specifications

Each axle carries **two discs:**

- **Natural disc** at 6.0mm from axle end
- **Sharp disc** at 8.0mm from axle end
- **Spacing:** 2.0mm between disc centers

**Disc geometry:**

- Elliptical profile (47 unique sizes)
- Radius range: 4.27mm (F7) to 25.0mm (C1)
- Material: Brass or bronze
- Thickness: 2-3mm

**Prongs:**

- **Two prongs per disc** (positioned 180° apart)
- Thread: M3×0.5 metric
- Total length: 18.7mm (12.7mm extension from disc surface)
- Material: 316 Stainless Steel
- Installation: Threaded into disc, secured with Loctite 243

### 4.3 Bearing System

**Total bearings:** 94 (two per axle)
**Types used:**

- 6008 (8mm ID): High-load bass strings
- 6006 (6mm ID): Medium strings
- 6905 (5mm ID): Medium-light strings
- 6904 (4mm ID): Treble strings
  **All bearings:** Deep groove ball bearings, 5mm width

**Mounting:**

- Left plate: Aluminum/carbon composite, 10mm thick
- Right plate: Aluminum/carbon composite, 10mm thick
- Bearing pockets: 5mm depth for press-fit installation
- Precision alignment via dowel pins

### 4.4 Disc Rotation Limits

**Critical design feature:** Discs do NOT rotate continuously. Maximum rotation is **approximately 45°**.

**Why rotation is limited:**

- String physically blocks further rotation
- Prongs engage string from above and below
- At 12:30 position, prongs are maximally engaging string
- Further rotation would cause prongs to collide with string

-----

## V. String System

### 5.1 String Specifications Summary

|Range|Count|Core Material|Wrap Material|Tension Range|
|-----|-----|---|---|---|
|C1-B1|7 |Steel/Nylon  |Bronze |217-237 N |
|C2-B2|7 |Steel/Nylon  |Bronze |210-226 N |
|C3-B3|7 |Nylon |Nylon/Bronze |127-210 N |
|C4-G4|5 |Nylon |None |108-129 N |
|A4-G7|21 |Nylon |None |49-106 N |

### 5.2 Disc Engagement Radii

**Engagement radius** = Disc radius + Prong extension (12.7mm)

Range: 16.97mm (F7) to 37.7mm (C1)

**Critical clearance:** String vibration amplitude varies from 0.3mm (G7) to 7.6mm (C1). Disc engagement radius must accommodate vibration while maintaining reliable prong contact.

### 5.3 String Positions (X-coordinates)

Strings positioned along X-axis from crown (0mm) to shoulder (721mm):

- C strings: 0.0, 107.4, 232.7, 351.0, 461.8, 565.6, 664.2 mm
- D strings: 0.0, 125.3, 250.6, 367.4, 477.2, 580.0, 677.5 mm
- E strings: 17.9, 143.2, 268.0, 383.8, 492.6, 594.4, 690.8 mm
- F strings: 35.8, 161.1, 285.4, 400.2, 508.0, 608.8, 704.1 mm
- G strings: 53.7, 179.0, 301.8, 415.6, 522.4, 623.2, 717.4 mm
- A strings: 71.6, 196.9, 318.2, 431.0, 536.8, 637.6 mm
- B strings: 89.5, 214.8, 334.6, 446.4, 551.2, 650.9 mm

-----

## VI. Neck Structure

### 6.1 Overall Dimensions

- **Length:** 720mm (X-direction, crown to shoulder)
- **Internal width:** 200mm (Y-direction, harpist to audience)
- **Internal height:** 250mm (Z-direction, vertical)
- **Material:** Hollow carbon fiber box beam
- **Wall thickness:** 5-10mm (optimized for stiffness-to-weight)

### 6.2 Internal Cavity Organization

**Upper routing channel:** Natural chain components
**Middle zone:** Disc axles and bearings
**Lower routing channel:** Sharp chain components
**Coupling linkages:** Vertical connections between chains at each string position

### 6.3 Mounting Plates

**Left plate (toward harpist):**

- Holds odd-numbered string axles
- Y-offset: -15mm
- Bearing pocket depth: 5mm
- Material: Aluminum or carbon composite

**Right plate (toward audience):**

- Holds even-numbered string axles
- Y-offset: +15mm
- Bearing pocket depth: 5mm
- Material: Aluminum or carbon composite

**Assembly method:**

- Bolted connection to neck structure
- Precision dowel pins for alignment
- Sealed to protect internal mechanism

### 6.4 Geometry

Neck slopes from crown to shoulder:

- Crown position: X=0, Z=1514.9mm (59.6 inches)
- Shoulder position: X=721mm, Z=1334.9mm (52.6 inches)
- Slope angle: -14.01° (downward from crown to shoulder)
- Height change: -180mm over 721mm length

-----

## VII. Pedal/Lever Control System

### 7.1 Input Method

**Traditional harp:** Foot pedals at pillar base
**Alternative (Clements47 option):** Hand levers at shoulder block

### 7.2 Pedal-to-Chain Connection

**For foot pedal control:**

1. Foot pedal at pillar base
1. Vertical rod up pillar (inside pillar cavity)
1. Rod emerges at crown
1. Clevis connection to master bell crank
1. Master bell crank drives natural chain

**For hand lever control:**

1. Lever at shoulder block (7 levers: C, D, E, F, G, A, B)
1. Push-pull rod (50-100mm, 6mm diameter, 316SS)
1. Lever bell crank (2:1 mechanical advantage)
1. Clamp collar connection to master bell crank input
1. Master bell crank drives natural chain

### 7.3 Three-Position Detent

**Location:** At pedal/lever input only (NOT at each disc)

**Mechanism:**

- Ball detent with spring preload
- Three dimples for Flat/Natural/Sharp positions
- Ball diameter: 3mm, hardened steel
- Spring: 3mm OD, 10mm length, 5N preload
- Force to move: 5-10N
- Adjustment: M4 screw for spring preload

**Position indication:**

- Tactile feedback via detent
- Optional visual indicator
- Optional color/shape coding for hand levers

-----

## VIII. Toggle Linkage Design Details

### 8.1 Four-Bar Linkage Analysis

The compound bell crank at each string position forms a four-bar linkage:

1. **Ground link:** Neck structure (fixed)
1. **Input link:** Arm from natural chain
1. **Coupler:** Bell crank body with two arms
1. **Output link:** Arm to sharp chain

**Toggle positions occur when links align** creating mechanical advantage approaching infinity (geometric lock).

### 8.2 Arm Angle Relationship

**Natural arm and sharp arm arranged ~90° apart on bell crank:**

When natural arm is at maximum displacement:

- Natural arm: Large angular sweep
- Sharp arm: Near its dead center (minimal motion)
- Toggle point approaching

When sharp arm is at maximum displacement:

- Sharp arm: Large angular sweep
- Natural arm: Near its dead center (minimal motion)
- Natural chain held by geometry

### 8.3 Mechanical Advantage Through Motion

**Position 0→1 (Natural engagement):**

- Input: Pedal/lever motion
- Natural arm MA: High (2:1 to 5:1 depending on position)
- Sharp arm MA: Very low (near dead center)
- Result: Natural discs rotate, sharp discs barely move

**Position 1→2 (Sharp engagement):**

- Input: Continued pedal/lever motion
- Natural arm MA: Very low (past toggle, near dead center)
- Sharp arm MA: High (2:1 to 5:1)
- Result: Sharp discs rotate, natural discs held

### 8.4 Lost Motion vs. Toggle Action

**Traditional lost motion:** Intentional slop/clearance in linkages
**Toggle action (used here):** Geometric dead centers create sequential motion without clearance

**Advantages of toggle over lost motion:**

- More positive positioning
- No accumulated wear from clearances
- Self-reinforcing (geometry holds position)
- Smoother operation

-----

## IX. Manufacturing Specifications

### 9.1 Bell Crank Fabrication

**Material:** Aluminum 6061-T6 plate or mild steel
**Processes:**

1. Laser/waterjet cutting of profile
1. CNC drilling of pivot hole and pin holes
1. Deburring and edge finishing
1. Anodizing (aluminum) or coating (steel)

**Critical dimensions:**

- Pivot hole: ±0.01mm for bearing fit
- Pin holes: ±0.02mm
- Arm lengths: ±0.1mm
- Arm angle: ±1°

**Tolerances matter:** Arm angle errors accumulate through chain, affecting final disc position.

### 9.2 Linkage Rod Production

**Material:** 316 Stainless Steel rod, 3-6mm diameter
**Processes:**

1. Cut to length (+2mm for threading)
1. Thread ends M6×1.0 or M4×0.7
1. Install rod end bearings or fabricate clevises
1. Inspect threads with go/no-go gauges

**Quality control:**

- Straightness: <0.1mm over length
- Thread engagement: Minimum 1.5× diameter
- Free rotation of rod ends: <0.5N breakaway torque

### 9.3 Disc Axle Machining

**Material:** 316 Stainless Steel rod, 4-8mm diameter
**Processes:**

1. CNC lathe: Turn to diameter ±0.005mm
1. Cut to length (44mm ±0.1mm)
1. Face ends perpendicular ±0.01mm
1. Deburr and polish bearing surfaces to Ra 0.8μm
1. Inspect diameter with micrometer

**Bearing fit critical:**

- Axle diameter: h6 tolerance (light press fit)
- Surface finish: <0.8μm Ra for bearing life
- Straightness: <0.02mm over length

### 9.4 Disc Fabrication

**Material:** Brass C360 or Bronze C510, 2-3mm plate
**Processes:**

1. CNC mill elliptical profile (47 unique profiles)
1. Drill center hole for axle (slip fit, +0.02mm)
1. Drill and tap M3×0.5 holes for prongs (2 per disc, 180° apart)
1. Deburr and polish edges
1. Mark disc with note/type (laser engraving)

**Quality control:**

- Prong hole position: ±0.1mm from center
- Prong hole perpendicularity: ±1°
- Disc radius: ±0.2mm
- Surface finish: Smooth to avoid string damage

**Assembly:**

1. Press disc onto axle at specified position (6.0mm or 8.0mm from end)
1. Pin or set screw to lock position
1. Thread M3 prongs into disc
1. Apply Loctite 243 to threads
1. Torque to 0.5 Nm (careful not to strip)

-----

## X. Assembly Procedures

### 10.1 Subassembly: Single-String Mechanism

**Components for one string:**

- 1 disc axle with 2 discs and 4 prongs installed
- 2 bearings pressed onto axle
- 2 bell cranks (one for natural chain, one for sharp chain)
- 1 compound bell crank (coupling linkage)
- Linkage rods to adjacent strings
- Hardware (pins, clips, washers)

**Assembly sequence:**

1. Press bearings onto disc axle
1. Install axle in mounting plate (appropriate side based on string number)
1. Attach natural bell crank to natural disc
1. Attach sharp bell crank to sharp disc
1. Install compound bell crank pivot
1. Connect natural arm to natural bell crank
1. Connect sharp arm to sharp bell crank
1. Test motion through 0→1→2 positions
1. Verify disc positions at each pedal position
1. Check for binding or interference

### 10.2 Chain Assembly

**For each note (C, D, E, F, G, A, B):**

1. Install all disc axles for that note (6-7 strings)
1. Install master bell crank at crown/input
1. Connect master to first string natural bell crank via linkage rod
1. Connect subsequent natural bell cranks via linkage rods
1. Connect all sharp bell cranks via linkage rods
1. Install compound bell cranks at each position
1. Test full chain motion
1. Adjust linkage rod lengths if needed
1. Verify all discs reach correct positions simultaneously

### 10.3 Neck Assembly Integration

**Complete harp assembly:**

1. Fabricate/obtain carbon fiber neck structure
1. Install left mounting plate with all odd-string axles
1. Install right mounting plate with all even-string axles
1. Route all 7 natural chains through upper channel
1. Route all 7 sharp chains through lower channel
1. Install compound bell cranks between chains
1. Connect master bell cranks to pedal/lever inputs
1. Install detent mechanisms at inputs
1. String the harp (start with low tension, gradually increase)
1. Test each string at all three positions
1. Fine-tune linkage adjustments
1. Verify no binding through full range
1. Seal neck cavity (dust covers, access panels)

-----

## XI. Adjustment and Tuning

### 11.1 Disc Position Calibration

**Objective:** All discs of a given note reach exactly 9:15, 12:30, 12:30 at pedal positions 0, 1, 2.

**Procedure:**

1. Set pedal to position 0 (flat)
1. Measure disc angles (should all be 9:15)
1. If disc is off, adjust linkage rod length to/from that disc
1. Repeat for position 1 (natural, 12:30)
1. Repeat for position 2 (sharp, 12:30)
1. Iterate until all discs synchronized

**Tools needed:**

- Angle gauge or protractor
- Linkage rod length adjustment (turnbuckle or threaded rod ends)
- Patience (this is iterative and time-consuming)

### 11.2 String Pitch Verification

**For each string, verify three pitches:**

Position 0 (Flat): String vibrates at “flat” frequency
Position 1 (Natural): String vibrates at “natural” frequency  
Position 2 (Sharp): String vibrates at “sharp” frequency

**Adjustment method:**

1. Tune string to “natural” pitch with pedal at position 1
1. Move pedal to position 0, measure pitch (should be flat)
1. If flat pitch is wrong, adjust disc angle at position 0
1. Move pedal to position 2, measure pitch (should be sharp)
1. If sharp pitch is wrong, adjust disc angle at position 2
1. Re-tune natural, verify all three pitches
1. Iterate until all three pitches correct

**This is the hardest part of harp setup** and can take hours per string for initial setup.

### 11.3 Action Feel Optimization

**Pedal/lever feel should be:**

- Smooth through entire range
- Distinct detent “clicks” at each position
- Consistent force required across all 7 pedals/levers
- No binding or sticking

**Adjustments:**

- Detent spring preload (increase for stronger click)
- Bearing preload (adjust if too tight or too loose)
- Linkage rod alignment (ensure rods pull straight, not at angles)
- Lubrication (light oil on bearings, dry graphite on pivots)

-----

## XII. Performance Specifications

### 12.1 Pitch Change Speed

**Mechanical limit:** Toggle linkage can change positions in ~0.1-0.3 seconds per string
**Practical limit:** Harpist technique limits to ~0.5-1.0 seconds for clean pitch change
**Advantage over manual levers:** All strings of a note change simultaneously

### 12.2 Reliability Targets

**Bearing life:** >10,000 hours (deep groove ball bearings, properly lubricated)
**Linkage wear:** Minimal wear with proper materials (steel pins in bronze/aluminum)
**Disc/prong life:** >100,000 cycles (stainless steel on brass/nylon string)
**Detent life:** >500,000 cycles (hardened steel ball on hardened dimples)

### 12.3 Maintenance Schedule

**Daily (performance harp):**

- Visual inspection of disc positions
- Check for loose hardware
- Wipe down exposed components

**Weekly:**

- Lubricate bearings (1 drop light oil per bearing)
- Check linkage rod connections
- Verify pedal/lever detent function

**Monthly:**

- Full mechanism inspection
- Re-calibrate disc positions if needed
- Check bearing play (replace if excessive)
- Clean and re-lubricate all pivots

**Annually:**

- Complete disassembly and inspection
- Replace worn bearings
- Re-surface or replace worn discs
- Replace worn prongs
- Refinish/re-coat components as needed

-----

## XIII. Comparison to Traditional Pedal Harp

### 13.1 Clements47 Advantages

**Mechanical:**

- Toggle linkage is simpler than piston/bell-crank systems
- Fewer parts than traditional crankshaft mechanisms
- Direct linkage (shorter power path, less lost motion)
- Self-reinforcing toggle positions (geometry holds discs)

**Practical:**

- Straight neck vs. curved (easier to manufacture)
- Shorter overall height (easier to transport)
- Modular design (chains can be serviced independently)
- Smaller footprint

**Cost:**

- Estimated 1/6 the cost of concert grand pedal harp
- Simpler manufacturing (no complex curved crankshafts)
- Standard bearings and hardware
- Carbon fiber construction reduces weight and cost

### 13.2 Traditional Harp Advantages

**Established design:**

- 200+ years of refinement
- Known reliability
- Established manufacturing processes
- Worldwide service network

**Sound:**

- Larger soundboard (curved geometry)
- Proven acoustic design
- Traditional aesthetic

### 13.3 Clements47 Trade-offs

**Accepts:**

- New mechanism requires validation
- Toggle linkage is novel (unproven in production harps)
- Straight geometry changes ergonomics slightly

**Gains:**

- Modern materials (carbon fiber, stainless steel)
- Portable design
- Accessible cost
- Simplified manufacturing

-----

## XIV. Design Status and Next Steps

### 14.1 Current Status

**Completed:**

- ✅ Complete string calculations (47 strings, tensions, frequencies)
- ✅ Disc geometry (47 unique sizes, prong specifications)
- ✅ Toggle linkage mechanism concept
- ✅ Bearing selection and specifications
- ✅ Coordinate system and geometry
- ✅ Material selection

**In Progress:**

- 🔄 Detailed CAD models of toggle linkage components
- 🔄 Finite element analysis of bell crank stresses
- 🔄 Kinematic simulation of toggle action
- 🔄 Manufacturing process documentation

**Not Started:**

- ⏸️ Physical prototype construction
- ⏸️ Acoustic testing
- ⏸️ Long-term reliability testing
- ⏸️ Cost optimization and supplier selection

### 14.2 Critical Validation Needed

**Mechanical validation:**

1. Build single-string prototype to verify toggle linkage concept
1. Test disc rotation limits and engagement angles
1. Verify sequential motion (natural first, then sharp)
1. Measure forces required at pedal input
1. Test for binding, backlash, and lost motion

**Acoustic validation:**

1. Verify disc engagement changes pitch correctly
1. Measure pitch accuracy at all three positions
1. Test for unwanted noise (disc/prong clicking)
1. Verify string vibration not impeded by disc proximity

**Durability validation:**

1. Cycle test linkage components (100,000+ cycles)
1. Accelerated wear testing on discs and prongs
1. Bearing life testing under load
1. String life testing with repeated pitch changes

### 14.3 Manufacturing Development

**Prototype phase:**

- CNC machining of all metal components
- 3D printing of test fixtures and alignment jigs
- Hand assembly with careful documentation
- Iterative design refinement

**Production phase:**

- Design for manufacturing (DFM) optimization
- Supplier selection and qualification
- Quality control procedures
- Assembly jigs and fixtures
- Production cost analysis

### 14.4 Recommended Prototype Sequence

**Phase 1: Single-String Proof of Concept**

- Build one complete mechanism for one string
- Validate toggle linkage sequential action
- Verify disc engagement and pitch changes
- Measure forces and travel distances
- **Cost estimate:** $500-1,000
- **Timeline:** 4-6 weeks

**Phase 2: Single-Note Chain (7 strings)**

- Build complete C-note mechanism (7 strings)
- Validate chain synchronization
- Test compound bell crank coupling
- Verify all discs reach positions simultaneously
- **Cost estimate:** $3,000-5,000
- **Timeline:** 8-12 weeks

**Phase 3: Full 47-String Prototype**

- Build complete harp mechanism
- Integration with soundboard and frame
- Full acoustic testing
- Playability evaluation by professional harpist
- **Cost estimate:** $15,000-25,000
- **Timeline:** 6-9 months

-----

## XV. Conclusion

The CLEMENTS47 represents a revolutionary approach to pedal harp design, using a **toggle linkage over-center mechanism** to achieve reliable three-position pitch changes without complex crankshafts or extensive detent systems.

**Key innovations:**

1. **Toggle linkage sequential actuation** creates natural→sharp transition through geometry rather than detents
1. **Limited disc rotation** (~45°) rather than continuous rotation simplifies design
1. **Dual chain architecture** separates natural and sharp actuation paths
1. **Compound bell cranks** with ~90° arm angles create toggle positions naturally
1. **Straight-line geometry** simplifies manufacturing compared to traditional curved necks

**The mechanism relies on fundamental mechanical engineering principles:**

- Four-bar linkage kinematics
- Over-center toggle positions
- Geometric dead centers creating sequential motion
- Mechanical advantage variation through range of motion

**Success depends on:**

- Precise manufacturing tolerances (disc angles, linkage lengths)
- Proper material selection (wear resistance, friction)
- Careful assembly and adjustment procedures
- Validation through prototype testing

The toggle linkage mechanism is elegant, simple, and potentially more reliable than traditional designs. However, it remains unproven in production harps and requires physical validation before production commitment.

**This design document provides the complete mechanical specification** needed to build a prototype and validate the concept. The next critical step is fabrication and testing of a single-string mechanism to prove the toggle linkage principle in practice.

-----

## Document Revision History

**Version 1.0** - January 5, 2026

- Initial complete design document
- Toggle linkage mechanism fully specified
- All 47 string specifications included
- Manufacturing and assembly procedures documented
- Based on corrected understanding of actual mechanism (no crankshaft with journal throws)

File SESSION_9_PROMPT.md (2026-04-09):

# CLEMENTS47 Session 9 - Timing Diagrams and Force Analysis

## Session Goal
Create accurate timing diagrams showing how discs rotate, prongs engage strings, and forces are applied to change pitch. Get the mechanical visualization correct before analyzing dynamics.

## Current Status - What Works
- Complete JSON specifications (clements47.json) with all 47 strings, discs, axles, bearings
- Correct understanding of mechanism: toggle linkage with dual natural/sharp chains
- Hand levers at shoulder (not foot pedals at crown)
- Lever positions: `\` (flat), `|` (natural), `/` (sharp)
- Disc rotation: 0Â° (9/3 o'clock horizontal) â†’ 90Â° (6/12 o'clock vertical) = 45Â° CW rotation
- ASCII diagrams showing correct layout

## Critical Issues to Fix

### 1. Prong Positioning (MOST IMPORTANT)
**WRONG:** Prongs are drawn centered on the disc edge
**CORRECT:** Prongs are TANGENT to the disc edge

Example for disc radius R=10mm, prong radius r=2mm:
- Prong center is at distance (R + r) from disc center
- At 0Â° (3 o'clock): prong center at (12, 0)
- At 90Â° (12 o'clock): prong center at (0, 12)
- At 180Â° (9 o'clock): prong center at (-12, 0)
- At 270Â° (6 o'clock): prong center at (0, -12)

### 2. Neck Position
**WRONG:** Neck drawn at natural disc level
**CORRECT:** Neck is ABOVE the discs - discs are inside/below the neck structure

The neck is the enclosure that contains the mechanism. View from side:
```
    â•â•â•â•â•â•â•â•â•â•â•â•â• Neck (top surface)
         (o|o)    Natural discs (horizontal line, all aligned)
         (o|o)    Sharp discs (staggered diagonally)
         |        Strings pass through
```

### 3. Tuning Pins
**WRONG:** Pins drawn as circles directly above strings
**CORRECT:** Strings come off pins at ~45Â° angle

From tuning pin, string goes diagonally down and back toward the soundboard:
```
    O  â† Tuning pin (round peg)
     \
      \  â† String at 45Â° angle
       |  â† String becomes vertical
```

### 4. Scale Relationships
All dimensions MUST come from clements47.json:
- `dr` = disc radius (4.27mm to 25.0mm)
- `pl` = prong length extension (12.7mm for all)
- Prong radius should scale: ~15% of disc radius
- String width should scale: ~15% of disc radius

## Files Provided in Archive

1. **clements47.json** - Complete specifications (47 strings, discs, axles)
2. **schema.json** - Field abbreviations decoder
3. **clements47.md** - Full design document with ASCII diagrams
4. **lever_positions.py** - Working text-based animation showing three positions
5. **lever_animation.py** - Working animated cycle through positions
6. **harp_profile.py** - BROKEN visualization (needs fixing)
7. **disc_prong_visualization.py** - Earlier attempt (has some useful code)

## What to Do First

### Step 1: Fix the Prong Tangent Geometry
Create a test plot showing ONE disc with TWO prongs correctly positioned as tangent circles:

```python
disc_center = (0, 0)
disc_radius = 10.0  # mm
prong_radius = 2.0  # mm

# Prong centers are at distance (disc_radius + prong_radius) from disc center
# At 0Â° (3 o'clock position):
prong1_center = (disc_radius + prong_radius, 0)

# At 180Â° (9 o'clock position):  
prong2_center = (-(disc_radius + prong_radius), 0)

# Draw disc
disc = Circle(disc_center, disc_radius, fill=False, edgecolor='blue', linewidth=2)

# Draw prongs (tangent to disc edge)
prong1 = Circle(prong1_center, prong_radius, fill=True, facecolor='red', edgecolor='darkred')
prong2 = Circle(prong2_center, prong_radius, fill=True, facecolor='red', edgecolor='darkred')
```

Verify visually that prongs are TANGENT (touching but not overlapping) the disc edge.

### Step 2: Create Correct Harp Profile
Using corrected prong geometry, create side-view showing:

1. **Base** (brown rectangle at bottom, Z=0 to Z=100)
2. **Soundboard** (curved line from base, use 9-point spline from JSON)
3. **Strings** (vertical lines, width scaled by disc size)
4. **Tuning pins** (at top, with strings coming off at 45Â°)
5. **Neck enclosure** (rectangular outline ABOVE the disc positions)
6. **Natural discs** (horizontal line at Z=1400, all aligned)
7. **Sharp discs** (staggered diagonal below naturals)
8. **Prongs** (tangent circles on disc edges)
9. **Lever** (at shoulder, showing `\` `/` or `|` position)

All using ACTUAL dimensions from clements47.json

### Step 3: Three-Position Comparison
Create side-by-side plots showing:
- Flat `\`: Prongs at 0Â°/180Â° (horizontal, 9/3 o'clock)
- Natural `|`: Natural prongs at 90Â°/270Â° (vertical, 6/12 o'clock), sharp still horizontal
- Sharp `/`: Both disc sets with vertical prongs

### Step 4: Timing Diagrams
Once visualization is correct, create plots showing:
- Lever position vs time
- Disc angles vs time (natural and sharp chains)
- Prong position vs time  
- String deflection vs time
- Force applied to string vs time

## Key Data from JSON

All C strings (use these for the profile):
- C1: X=0.0mm, disc_r=25.0mm (largest, bass)
- C2: X=107.4mm, disc_r=21.75mm
- C3: X=232.7mm, disc_r=16.33mm
- C4: X=351.0mm, disc_r=9.42mm
- C5: X=461.8mm, disc_r=6.17mm
- C6: X=565.6mm, disc_r=5.2mm
- C7: X=664.2mm, disc_r=4.41mm (smallest, treble)

All prongs: 12.7mm extension from disc surface

## Success Criteria

You know you've succeeded when:
1. âœ“ Prong circles are tangent to (touching) disc circles
2. âœ“ Disc sizes scale correctly (C1 largest, C7 smallest)
3. âœ“ Prong sizes scale with disc size (~15% of disc radius)
4. âœ“ String widths scale with disc size
5. âœ“ Neck is drawn ABOVE the disc positions
6. âœ“ Tuning pins show strings coming off at 45Â° angle
7. âœ“ Sharp discs stagger diagonally from C7 to C1
8. âœ“ Natural discs all align horizontally
9. âœ“ Visualization matches the ASCII diagram layout

## Questions to Answer in Next Session

1. What force do the prongs apply to the string?
2. How much does the string deflect (1-5mm)?
3. How fast do the discs rotate (timing)?
4. What is the engagement sequence timing (natural first, then sharp)?
5. Does the toggle mechanism properly hold the natural discs while sharp engages?

## Notes

- The mechanism is identical to traditional pedal harps, just driven from shoulder instead of crown
- The JSON is complete and accurate - trust the numbers
- The ASCII diagrams are correct - match them
- Focus on getting ONE disc+prongs correct before doing all 47
- No titles, legends, or labels needed - just the clean visualization

## Previous Session Issues

We struggled with:
1. Prong positioning (kept putting them at wrong radius)
2. Understanding the tangent geometry
3. Scaling all components correctly
4. Removing unnecessary labels/titles
5. Getting the mechanical layout to match ASCII diagram

Don't repeat these mistakes - start with the tangent geometry test first!

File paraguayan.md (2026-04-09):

```

# SIDE VIEW

     Soundboard (╱) at 65° angle from horizontal, with piezos (●) mounted along it at ~33mm intervals.

       ◐◑◐◑◐◑◐◐◑◐◑◐◑◑◐◑◐◑◐◑◐◑◐◑◐◑◐◑◐◑◐◑◐◑◐◑◐◑◐◑◐◑◐◑◐◑◐      ← 47 Tuning pins +Z ◑ left, -Z ◐ right
  ┏━━┳━━━━━━━━━━━━━━━━━━━━━━━━━━━━━━━━━━━━━━━━━━━━━━━━━━━━┓ ← Neck
  ┣━━╋━━━━━━━━━━━━━━━━━━━━━━━━━━━━━━━━━━━━━━━━━━━━━━━━━━━━┛ ← Neck
  ┃  ┃ |||||||||||||||||||||||||||||||||||||||||||||||╱● ╱  ← G7 \ (string 47)
  ┃  ┃ ||||||||||||||||||||||||||||||||||||||||||||||╱● ╱   ← F7 |
  ┃  ┃ |||||||||||||||||||||||||||||||||||||||||||||╱● ╱    ← E7 |
  ┃  ┃ ||||||||||||||||||||||||||||||||||||||||||||╱● ╱     ← D7 |
  ┃  ┃ |||||||||||||||||||||||||||||||||||||||||||╱● ╱      ← C7 |
  ┃  ┃ ||||||||||||||||||||||||||||||||||||||||||╱● ╱       ← B6 |
  ┃  ┃ |||||||||||||||||||||||||||||||||||||||||╱● ╱        ← A6 | [Teensy 3: B5-G7]
  ┃  ┃ ||||||||||||||||||||||||||||||||||||||||╱● ╱         ← G6 |
  ┃  ┃ |||||||||||||||||||||||||||||||||||||||╱● ╱          ← F6 |
  ┃  ┃ ||||||||||||||||||||||||||||||||||||||╱● ╱           ← E6 |
  ┃  ┃ |||||||||||||||||||||||||||||||||||||╱● ╱            ← D6 |
  ┃  ┃ ||||||||||||||||||||||||||||||||||||╱● ╱             ← C6 |
  ┃  ┃ |||||||||||||||||||||||||||||||||||╱● ╱              ← B5 /
  ┃  ┃ ||||||||||||||||||||||||||||||||||╱● ╱               ← A5 \
  ┃  ┃ |||||||||||||||||||||||||||||||||╱● ╱                ← G5 |
  ┃  ┃ ||||||||||||||||||||||||||||||||╱● ╱                 ← F5 |
  ┃  ┃ |||||||||||||||||||||||||||||||╱● ╱                  ← E5 |
  ┃  ┃ ||||||||||||||||||||||||||||||╱● ╱                   ← D5 |
  ┃  ┃ |||||||||||||||||||||||||||||╱● ╱                    ← C5 |
  ┃  ┃ ||||||||||||||||||||||||||||╱● ╱                     ← B4 |
  ┃  ┃ |||||||||||||||||||||||||||╱● ╱                      ← A4 |  [Teensy 2: F3-A5]
  ┃  ┃ ||||||||||||||||||||||||||╱● ╱    ∠65°               ← G4 |
  ┃  ┃ |||||||||||||||||||||||||╱● ╱                        ← F4 |
  ┃  ┃ ||||||||||||||||||||||||╱● ╱                         ← E4 |
  ┃  ┃ |||||||||||||||||||||||╱● ╱                          ← D4 |
  ┃  ┃ ||||||||||||||||||||||╱● ╱                           ← C4 |
  ┃  ┃ |||||||||||||||||||||╱● ╱                            ← B3 |
  ┃  ┃ ||||||||||||||||||||╱● ╱                             ← A3 |
  ┃  ┃ |||||||||||||||||||╱● ╱                              ← G3 |
  ┃  ┃ ||||||||||||||||||╱● ╱                               ← F3 /
  ┃  ┃ |||||||||||||||||╱● ╱                                ← E3 \
  ┃  ┃ ||||||||||||||||╱● ╱                                 ← D3 |
  ┃  ┃ |||||||||||||||╱● ╱                                  ← C3 |
  ┃  ┃ ||||||||||||||╱● ╱                                   ← B2 |
  ┃  ┃ |||||||||||||╱● ╱                                    ← A2 |
  ┃  ┃ ||||||||||||╱● ╱                                     ← G2 |
  ┃  ┃ |||||||||||╱● ╱                                      ← F2 |
  ┃  ┃ ||||||||||╱● ╱                                       ← E2 | [Teensy 1: C1-E3 with bluetooth]
  ┃  ┃ |||||||||╱● ╱                                        ← D2 |
  ┃  ┃ ||||||||╱● ╱                                         ← C2 |
  ┃  ┃ |||||||╱● ╱                                          ← B1 |
  ┃  ┃ ||||||╱● ╱                                           ← A1 |
  ┃  ┃ |||||╱● ╱                                            ← G1 |
  ┃  ┃ ||||╱● ╱                                             ← F1 |
  ┃  ┃ |||╱● ╱                                              ← E1 |
  ┃  ┃ ||╱● ╱                                               ← D1 |
  ┃  ┃ |╱● ╱                                                ← C1 /  (string 1)
  ┃  ┃ ╱● ╱
  ┃   ╱  ╱
  ┃  ╱  ╱
  ┣━━━━┓
  ┃⏻══════════════  ← pedals d c b | e f g a
  ┗━━━━┛            ← base

       ⬁
        ⏻ 3 position toggle switches controlled by pedal position (up=flat, middle=natural, down=sharp)

# FRONT VIEW PILLAR

    Z=0
     ↓
    ┏━┓
    ┃ ┃   necks rest here on either side of the pillar
  ┏━┛ ┗━┓
  ┃     ┃
  ┃     ┃
  ┃     ┃
  ┃     ┃
  ┃     ┃
  ┃     ┃
  ┃     ┃
  ┃     ┃
  ┃     ┃  pillar (front view)
  ┃     ┃
  ┃     ┃
  ┃     ┃
  ┃     ┃
  ┃     ┃
  ┃     ┃
  ┃     ┃
  ┃     ┃
  ┃     ┃
  ┃     ┃
  ┃     ┃
  ┃ ┏━┓ ┃
  ┃ ┃ ┃ ┃ soundboard inserts into the slot
  ┗━┛ ┗━┛
     ↑
    Z=0

# FRONT VIEW SOUNDBOARD

  Z=0
   ↓
  ┏━┓
  ┃ ┃
  ┃ ┃
  ┃ ┃
  ┃ ┃
  ┃ ┃
  ┃ ┃
  ┃ ┃
  ┃ ┃
  ┃ ┃
  ┃ ┃
  ┃ ┃
  ┃ ┃
  ┃ ┃
  ┃ ┃
  ┃ ┃
  ┃ ┃
  ┃ ┃
  ┃ ┃
  ┃ ┃
  ┃ ┃
  ┃ ┃
  ┃ ┃
  ┗━┛
   ↑
  Z=0

# REAR VIEW NECK

    Z=0
     ↓
   ◐   ◑   ← 47 Tuning pins +Z ◐ left, -Z ◑ right
  ┏━┓ ┏━┓
  ┃ ┃ ┃ ┃
  ┃ ┃ ┃ ┃
  ┗━┛ ┗━┛
     ↑
    Z=0

```

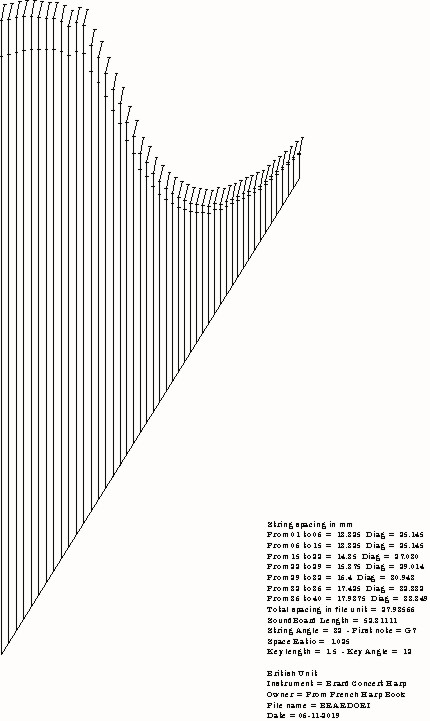
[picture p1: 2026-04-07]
erard template.jpg

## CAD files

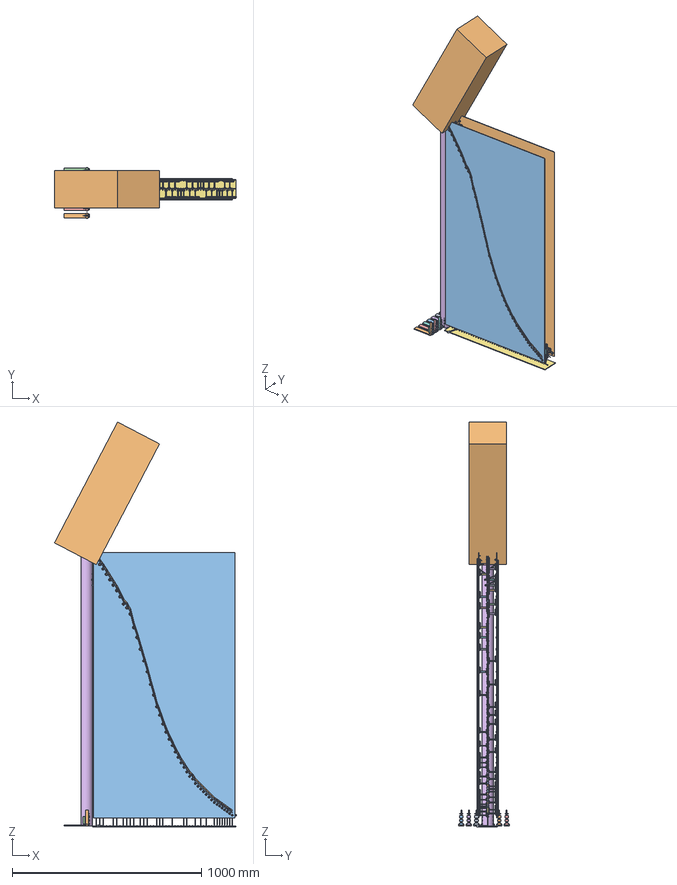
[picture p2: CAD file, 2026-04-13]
Clements47.FCStd
962.0 x 270.0 x 2138.9 mm
Soundbox
Str_G7
Str_F7
Str_E7
Str_D7
Str_C7
Str_B6
Str_A6
Str_G6
Str_F6
Str_E6
Str_D6
Str_C6
Str_B5
Str_A5
Str_G5
Str_F5
Str_E5
Str_D5
Str_C5
Str_B4
Str_A4
Str_G4
Str_F4
Str_E4
Str_D4
Str_C4
Str_B3
Str_A3
Str_G3
Str_F3
Str_E3
Str_D3
Str_C3
Str_B2
Str_A2
Str_G2
Str_F2
Str_E2
Str_D2
Str_C2
Str_B1
Str_A1
Str_G1
Str_F1
Str_E1
Str_D1
Str_C1
Axle_G7
NatDisc_G7
NatPrU_G7
NatPrD_G7
ShpDisc_G7
ShpPrU_G7
ShpPrD_G7
Axle_F7
NatDisc_F7
NatPrU_F7
NatPrD_F7
ShpDisc_F7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

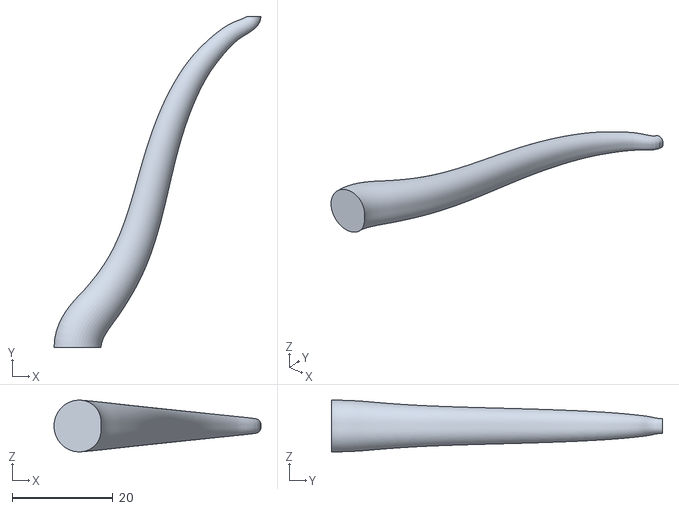
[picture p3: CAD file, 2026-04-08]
soundbox.obj
41.0 x 65.7 x 10.3

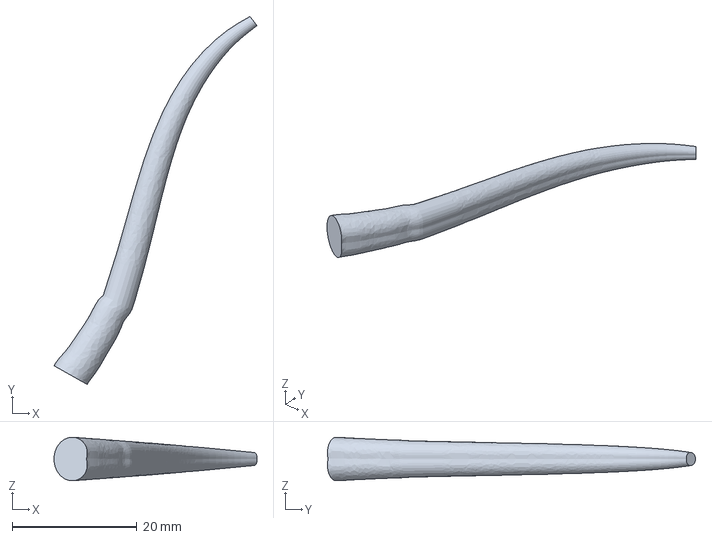
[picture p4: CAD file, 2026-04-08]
erard_harp.FCStd
32.5 x 59.0 x 6.97 mm

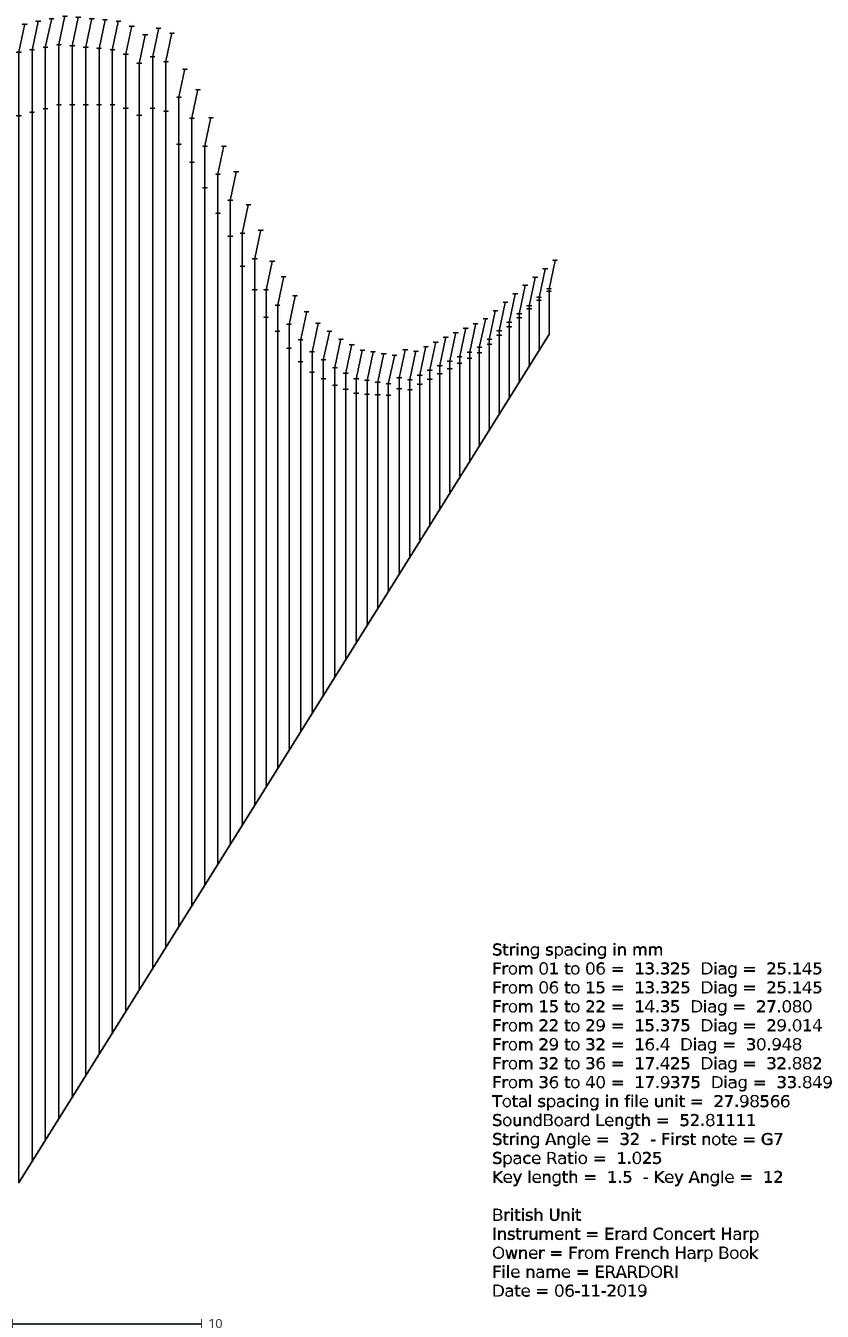
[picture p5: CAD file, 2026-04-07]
erard%20original%20stringband%20tutorial.dxf
String spacing in mm
From 01 to 06 = 13.325 Diag = 25.145
From 06 to 15 = 13.325 Diag = 25.145
From 15 to 22 = 14.35 Diag = 27.080
From 22 to 29 = 15.375 Diag = 29.014
From 29 to 32 = 16.4 Diag = 30.948
From 32 to 36 = 17.425 Diag = 32.882
From 36 to 40 = 17.9375 Diag = 33.849
Total spacing in file unit = 27.98566
SoundBoard Length = 52.81111
String Angle = 32 - First note = G7
Space Ratio = 1.025
Key length = 1.5 - Key Angle = 12
British Unit
Instrument = Erard Concert Harp
Owner = From French Harp Book
File name = ERARDORI
Date = 06-11-2019

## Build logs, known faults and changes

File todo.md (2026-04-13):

# Clements47 Part Inspection TODO

Parts added 2026-04-13 from ML Harps reference image analysis. All are placeholder geometry — correct topology/position but simplified shapes. Open in FreeCAD and compare against `images/` reference frames.

## Priority 1: Mechanically Critical (shape affects function)

- [ ] **Bell cranks** (Crank_C1..G7) — Currently rectangular arms + cylindrical boss. Reference (frame 0007) shows organic V-shaped compound cranks with curved profiles. Arm angles, lengths, and boss diameter affect toggle linkage geometry directly.
- [ ] **Coupling links** (NatLink_*/ShpLink_*) — Simple cylinder + disc clevises. Reference (frame 1209) shows machined parts with specific fork geometry. Length and pivot geometry affect dead-point position.
- [ ] **Disc rotation stops** (NatStop_*/ShpStop_*) — 4mm cubes at 60 deg. Actual stop angle and contact surface determine disc travel limit (~45 deg). Verify against reference frames 0943+.
- [ ] **Rocker levers** (Rocker_C..B) — Simple L-shape at column top. Reference (frame 0943) shows animated bell crank with specific arm ratio. Lever ratio sets pedal-to-disc force multiplication.

## Priority 2: Fit and Assembly (shape affects neighboring parts)

- [ ] **Bearings** (BrgF_*/BrgB_*) — Generic flanged sleeves. Reference (frame 0142) shows specific ball bearing housings (6008/6006/6905/6904 series). OD, width, and flange dimensions should match actual bearing specs from JSON `b` field.
- [ ] **Spindle nuts** (NatNut_*/ShpNut_*) — Cylindrical approximation of hex nuts. Should be hexagonal. Sharp disc nuts need LEFT-HAND thread indication.
- [ ] **Guide rails** (NatRailU/L, ShpRailU/L) — Follow pin line with Y offset. Reference (frame 0134) shows them curving with the neck between action plates, with bracket mounts. Need to verify path and add mounting brackets.
- [ ] **Action plates** (FrontPlate/BackPlate) — Flat rectangles with bearing holes. Reference (frames 0360, 0429) shows contoured plates following the neck curve, with mounting features and cutouts.
- [ ] **Tuning pins** (Pin_C1..G7) — Plain cylinders. Real tuning pins have a tapered tip, a squared drive end, and thread for the string wrap.

## Priority 3: Structural (shape affects appearance)

- [ ] **Column** (Column) — Plain hollow cylinder at x=-50. Real column (visible throughout as dark striped element) is tapered, possibly fluted, and connects to both base and neck with specific joint geometry.
- [ ] **Pedal assembly** (Pedal_*/NotchPlate_*/PedalSpring_*) — Very schematic. Real pedals (reference frames 0943-1118) have forged lever arms, proper spring housings, and cast zigzag notch plates. Standard order D C B | E F G A needs verification.
- [ ] **Soundboard** (Soundboard) — Flat 100mm-wide rectangle at z=0. Should follow limacon profile width (wider at bass, narrower at treble). Thickness taper typical of spruce soundboards. **Blocked by soundbox alignment decision (Option A vs B).**
- [ ] **Grommets** (Grommet_C1..G7) — Simple annular rings. Real grommets have a flanged collar and may be recessed into the soundboard.

## Priority 4: Springs (cosmetic for static model)

- [ ] **Pedal springs** (PedalSpring_*) — Hollow cylinders. Should be helical coil geometry if visual fidelity matters.
- [ ] **Return springs** (ReturnSpring_*) — Hollow cylinders at rocker pivots. Should be torsion spring geometry.

## Still Unresolved

- [ ] **Soundbox alignment** — Option A (straight along X in mm) vs Option B (smooth curve centerline). Blocks soundboard, grommet, and string endpoint corrections. Choose before refining any z=0 parts.
- [ ] **Linkage rod cross-sections** — Buckwell patent notes tension vs compression links have DIFFERENT cross-sections. Currently all 3mm round.
- [ ] **Treble disc prong count** — Camac manual says F7-F0 have only 1 prong (space constraint). Currently all discs have 2 prongs.

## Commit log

2026-04-07 Add Erard concert harp stringband sketch and FreeCAD macro
    Parsed string positions from DXF data (harpcanada.com), built a fully
    constrained FreeCAD Sketcher with 47 strings, key segments, spacing,
    and a smoothing-spline soundboard curve (k=5, s=0.5).
    [erard%20original%20stringband%20tutorial.dxf, erard_harp.FCStd]
2026-04-07 Top-aligned pins with smoothed soundboard B-spline constrained in sketch
    - Pins top-aligned at Y=0, string lengths smoothed (k=5, s=0.5)
    - Soundboard is now a constrained B-spline inside the sketch using
    FreeCAD 1.1 exposeInternalGeometry with 7 control points
    - Fully constrained, 0 DOF, 0 kinks in soundboard curve
    [erard_harp.FCStd]
2026-04-07 Add 3D soundbox with 47 limaçon cross-sections lofted along soundboard
    - Limaçon D-shape profiles perpendicular to soundboard curve at each grommet
    - Diameter scales linearly from 10" (bass) to 3" (treble)
    - a/b ratio = 1.5 (no loop, smooth D-shape)
    - Combined sketch + soundbox into single macro
    [erard_harp.FCStd]
2026-04-08 Rebuild soundbox with cardioid limaçons (a==b) and Erard string diameters
    - 47 cardioid cross-sections (a==b) with cusp at string bottom, flat side up
    - Diameter tapers 10" (bass) to 3" (treble), lofted into solid soundbox
    - 47 3D string cylinders with Erard gauge diameters from harpcanada.com
    - Stringband sketch with vertical constraints, spacing, key segments, B-spline
    - String data from original DXF, normals from erard_harp.FCMacro
    [clements47.FCStd]
2026-04-08 Fix limaçon orientation: cusp faces up, body hangs below soundboard
    - Flipped normal direction so round body extends below/behind soundboard
    - Cusp (flat side) at string bottom faces up toward pins
    - Confirmed a==b (cardioid), 120-point interpolation for smooth shape
    - Diameter 10" bass to 3" treble, volume=990.77 cu in
    [clements47.FCStd]
2026-04-08 Soundbox with a=2b limaçons (convex, flat top) and add CLAUDE.md
    - Limaçon r = a + b·cos(θ) with a=2b: convex shape, flat on soundboard side
    - String 1: a=3.333, b=1.667, dia=10". String 47: a=1.0, b=0.5, dia=3"
    - Body hangs below soundboard (negated normals), flat side faces up toward pins
    - Added CLAUDE.md with full model docs for future Claude Code sessions
    [clements47.FCStd]
2026-04-08 Fix limaçon origin: flat side now touches string bottoms at both ends
    - Shifted polar origin by b along normal so theta=pi point (flat side)
    lands exactly on string bottom, not the polar center
    - Limacon 1 to string 1: 0.000000" gap
    - Limacon 47 to string 47: 0.000000" gap
    - a=2b unchanged, volume=1353.48 cu in
    [clements47.FCStd]
2026-04-08 Redesign soundbox with parametric limaçon surface from two spline curves
    Soundboard curve (11-node clamped cubic spline) with vertical takeoff
    at base and neck, plus cusp curve (9-node) derived by offsetting along
    the right normal. Limaçon cross-sections (a=2b) are generated from
    origin/cusp pairs with diameter tapering 18" to 4". 50 sections lofted
    into solid. Added full documentation of surface generation formulas.
    [Clements47.FCStd, erard_harp.FCStd]
2026-04-08 Add string analysis and stringband data to README
    - HSA-based string analysis (47 strings): tensions, stress, breaking %
    - Total soundboard load: 2,261 lbs
    - Full note map with materials, colors, diameters, frequencies
    - Material properties (nylon, gut, steel wire)
    - US string supplier references
    - Smoothed soundboard SVG (s=0.03 weighted, bezier export)
    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
    [clements47_string_analysis.csv, soundbox.obj]
2026-04-08 Update string analysis with professional Bow Brand specs
    Nylon top 3 + Bow Brand Pedal Gut standard (4-35) + Wire bass (36-47).
    Real diameters from harpstrings.biz. Total load 1,865 lbs, max 69.8%
    breaking strength. Includes tension jumps and material transition analysis.
    [clements47_string_analysis.csv]
2026-04-08 Update to original Erard string specs from harpcanada.com
    All-nylon design (not gut): plain nylon 1-27, nylon-wound 28-38,
    steel/bronze 39-47. Total tension 1,466 lbs. Added US sourcing
    plan with Dusty Strings, Musicmakers, Vanderbilt, Aquila.
    [clements47_string_analysis.csv]
2026-04-08 Update soundboard and mesh with verified Erard string lengths
    Lengths from harpcanada.com/harpmaking/erard.htm match DXF within 0.39".
    Pin spread 1.26". Soundbox mesh regenerated with 100 sections.
    [soundbox.obj]
2026-04-08 Add acoustic analysis, smooth bezier curves, complete SVG
    - Soundbox volume 66L, Helmholtz resonance 69 Hz (C2)
    - Comparison with Lyon & Healy and Salvi concert harps
    - Tonal predictions and design recommendations
    - SVG: smooth bezier soundboard + cusp curves with vertical takeoffs,
    horizontal base/neck limacons, color-coded strings, key segments,
    natural/sharp/grommet dots, red pin dots, gray pin line
    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
    [soundbox.obj]
2026-04-08 Smooth cusp curve with adjusted bezier handles at endpoints
    Curvature jumps at segment boundaries reduced to <0.004 in the
    string area. Longer handles (40%) at base/neck end segments for
    gradual curvature transition. Both SVG and OBJ updated.
    [soundbox.obj]
2026-04-08 Generate Clements47.FCStd from smooth bezier soundboard curve
    70 limacon sections lofted into solid. Bezier curve with vertical
    takeoffs at base/neck, weighted smoothing (s=0.05) in string area.
    Diameter 18" base to 4" neck, a=2b limacon ratio.
    [Clements47.FCStd]
2026-04-08 Fix soundbox to reach neck - evenly space sections by arc length
    Previous version skipped the last bezier segment, stopping short of
    the neck. Now 70 sections distributed uniformly along 75.4" curve
    from base (7.0,-65.6) to neck (40.4,0.0).
    [Clements47.FCStd]
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2026-04-08 Reduce base diameter to 14" for 43L volume (1.2x modern harps)
    Was 18" (66L, nearly 2x modern). Now 14" base, 4" neck = 43L.
    Helmholtz resonance ~85 Hz (E2). Dimensions match modern concert
    harp range (14-16" base). All files regenerated: SVG, OBJ, FCStd, macro.
    [Clements47.FCStd, soundbox.obj]
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2026-04-11 Smooth soundboard curve via 9-pt cubic clamped fit; cross-machine handoff
    The visible kink between strings 10 and 11 in the soundbox loft was
    traced to the smoothed string_lengths array in erard_harp.FCMacro line
    140 -- string 11 length 48.1801 sticks out by ~1" from a smooth
    interpolation of its neighbors. String lengths and spacings are
    immutable per user constraint, so the kink can only be moved (not
    deleted) by relaxing pins from y=0.
    fix_soundbox.py (new) builds the soundboard centerline as a scipy
    CubicSpline through 9 anchor points (strings 1, 6, 12, 18, 24, 30, 36,
    42, 47) with clamped endpoint tangents (bass +1.467, treble +0.740)
    derived from least-squares of the first/last 5 raw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
    [Clements47.FCStd]
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2026-04-13 Add 438 missing mechanism parts (577->1015 objects): bearings, pedals, soundboard, etc.
    New parts from ML Harps reference image analysis:
    - 94 bearings, 94 spindle nuts, 4 guide rails, 47 tuning pins
    - Column, 7 pedal rods, 7 rocker levers
    - 14 coupling links, 7 pedals with notch plates and springs
    - Soundboard, 47 grommets, 94 disc rotation stops, 7 return springs
    Complete mechanical chain from pedal to disc now modeled.
    [Clements47.FCStd]
